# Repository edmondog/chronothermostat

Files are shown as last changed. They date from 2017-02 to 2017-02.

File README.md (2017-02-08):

# chronothermostat
Homebrewed room by room themperature control

Very rough i2c control for the temperature sensor (texas tmp 102 http://www.ti.com.cn/cn/lit/ds/symlink/tmp102.pdf)
The board has:
4 digit 7seg led display
1 encoder
1 pushbutton
485 serial interface
2 tempeature sensors
1 AC triac switch
ATMEGA328p cpu

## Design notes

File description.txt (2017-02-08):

The board controls the temperature of the room reading a tmp102 and switching a fan.
A second tmp102 controls the temperature of the heating part to avoid turning on the fan if no heat is available.
The display normally shows the room temperature.
The setpoint value is shown when pushing the button.
To avoid unwanted setpoint changing, the modification of the setpoint is subjected to password control.
The password is inserted as a number that has to be dialed using the encoder knob.
The password is fixed in code (33); once dialed the setpoint is shown and can be modified turning the encoder.
Under password 22 the temperature of the heater is shown
Under password 44 the 485 board ID is shown and made editable
A minimal communication protocol is made available to allow remote monitoring and control by a remote pc, actually a Raspberry pi.

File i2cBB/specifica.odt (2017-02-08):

Per accedere alle funzioni:

selezionare il numero relativo alla funzione e premere il pulsante.

F. 33 setpoint temperatura

F 44 indirizzo scheda

richiesta ventil e temperatura:

@xR0<CR>

vTTTT<CR>

x=indirizzo scheda

v=stato ventil

TTTT=temperatura attuale

richiesta setpoint:

@xR1<CR>

SSSS<CR>

x=indirizzo scheda

SSSS=setpoint

set setpoint:

@xW1SSSS<CR>

OK<CR>

x=indirizzo scheda

SSSS=setpoint

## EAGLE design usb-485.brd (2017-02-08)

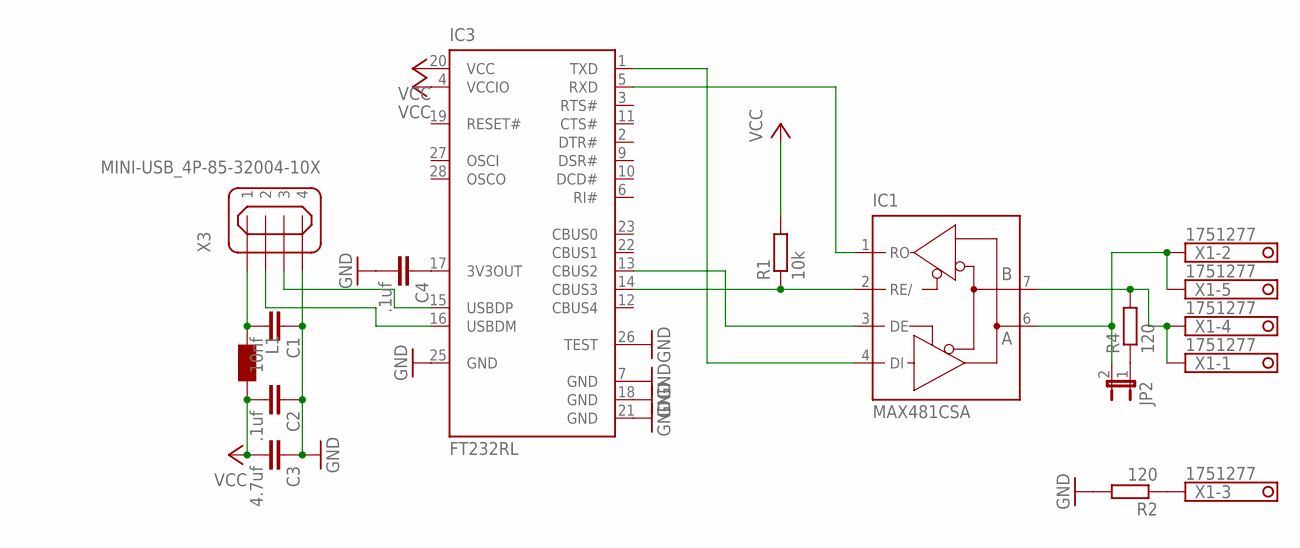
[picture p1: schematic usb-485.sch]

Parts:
C1: 10nf; C0805
C2, C4: .1uf; C1206
C3: 4.7uf; C1206
IC1: MAX481CSA; SO08
IC3: FT232RL; SSOP28
JP2: JP1E; JP1
L1: WE-CBF_1206; 1206
R1: 10k; 0207/10
R2, R4: 120; 0207/10
X1: 1751277
X3: MINI-USB_4P-85-32004-10X; 85-32004-10X

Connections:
GND: C1.1, C2.1, C3.1, C4.2, IC1.5 (GND), IC3.7 (GND), IC3.18 (GND), IC3.21 (GND), IC3.25 (GND), IC3.26 (TEST), R2.2, X3.4
unnamed: IC1.3 (DE), IC3.13 (CBUS2)
unnamed: IC1.2 (RE/), IC3.14 (CBUS3), R1.1
unnamed: IC1.7 (B), R4.2, X1.1, X1.4
unnamed: R2.1, X1.3
unnamed: JP2.1, R4.1
unnamed: C1.2, L1.1, X3.1
unnamed: IC1.6 (A), JP2.2, X1.2, X1.5
unnamed: IC3.16 (USBDM), X3.2
unnamed: IC3.15 (USBDP), X3.3
unnamed: C4.1, IC3.17 (3V3OUT)
unnamed: IC1.1 (RO), IC3.5 (RXD)
unnamed: IC1.4 (DI), IC3.1 (TXD)
VCC: C2.2, C3.2, IC1.8 (VCC), IC3.4 (VCCIO), IC3.20 (VCC), L1.2, R1.2

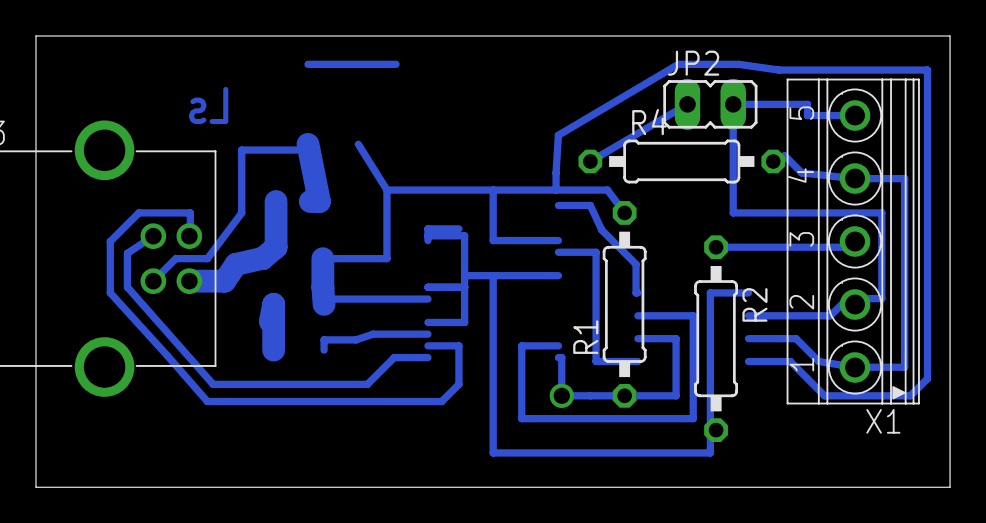
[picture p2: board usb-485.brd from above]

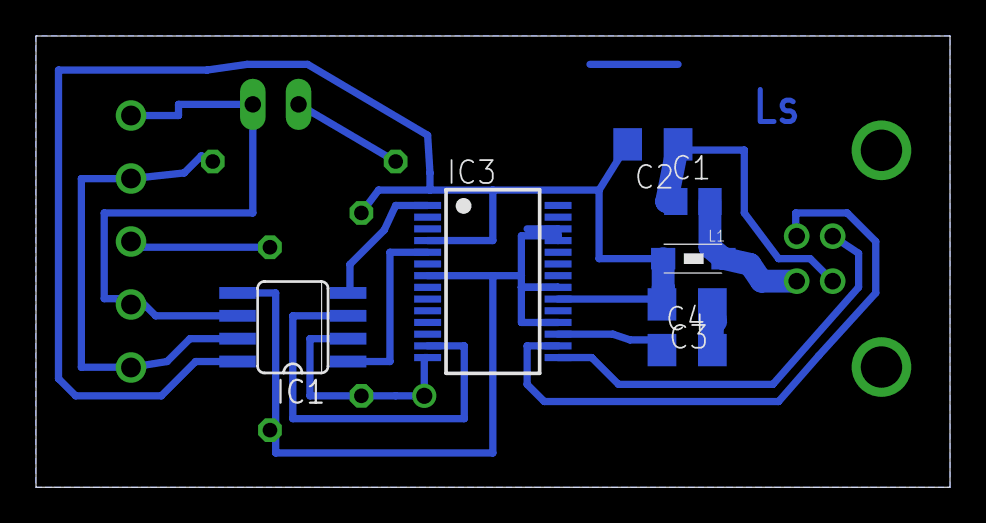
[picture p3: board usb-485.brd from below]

Board: 2 copper layers, 50.8 x 25.1 mm, 13 parts (7 on the bottom side), 14 nets.

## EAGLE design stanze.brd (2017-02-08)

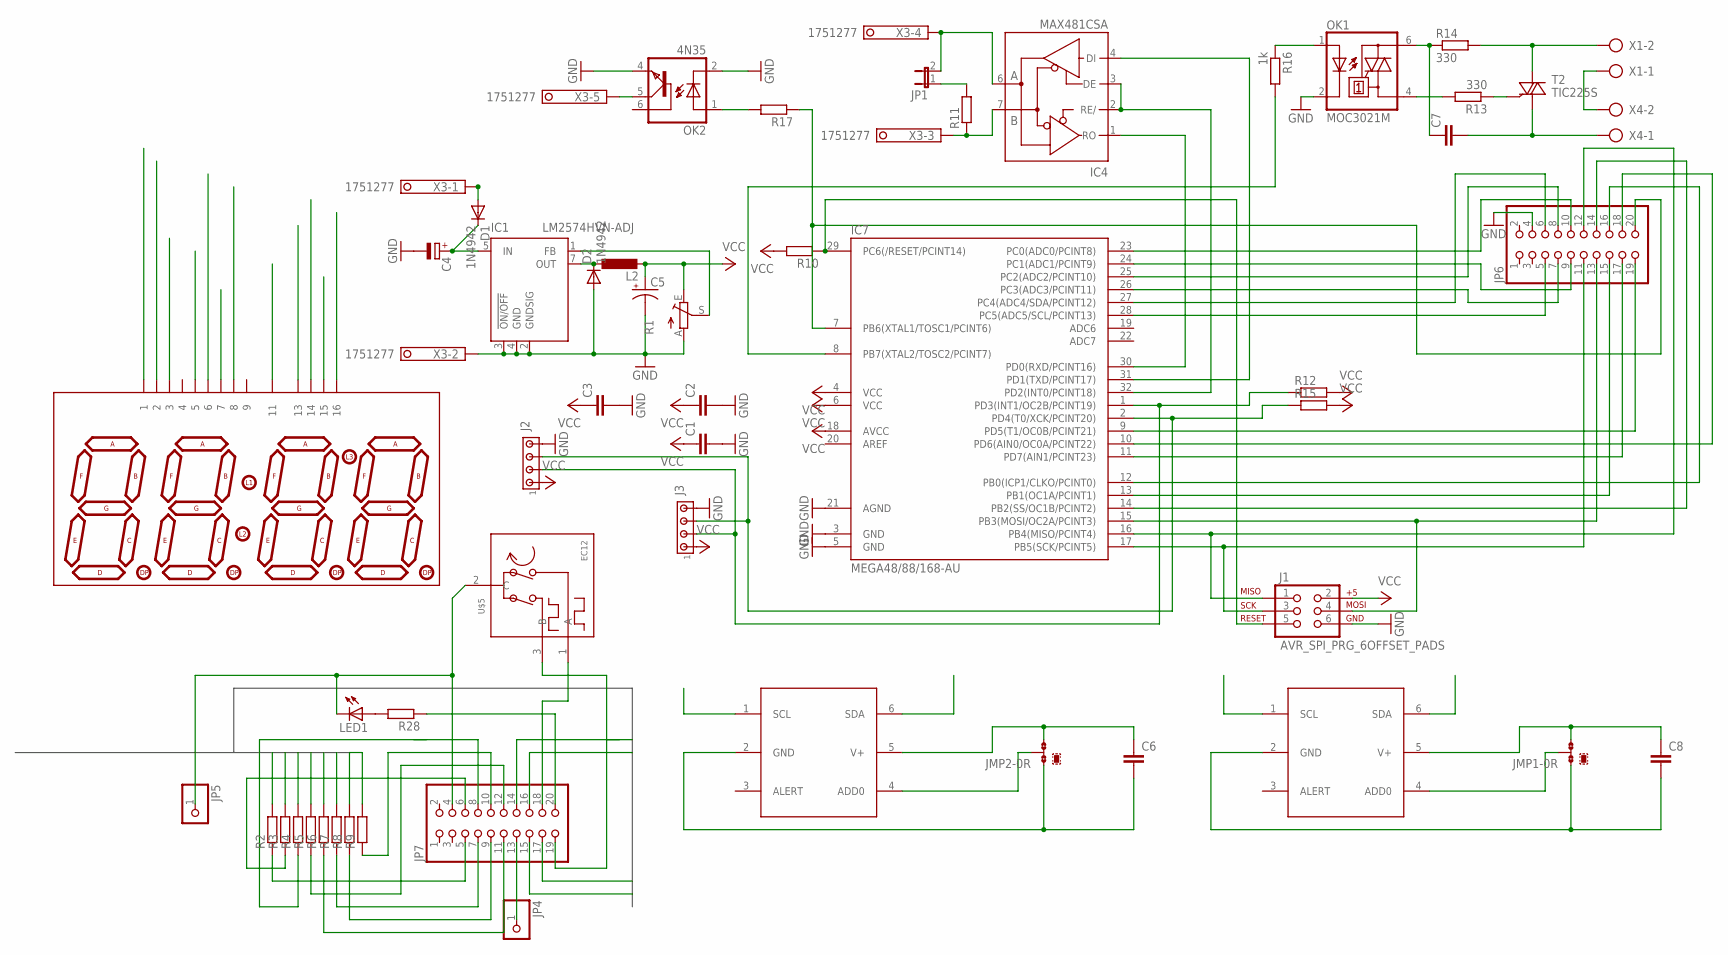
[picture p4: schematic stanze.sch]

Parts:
C1, C2, C3: C-EUC1206; C1206
C4: CPOL-EUE2,5-6E; E2,5-6E
C5: CPOL-USE5-10.5; E5-10,5
C6, C8: C-EUC0805; C0805
C7: C-EU075-032X103; C075-032X103
D1, D2: 1N4942; DO41-10
IC1: LM2574HVN-ADJ; DIL08
IC4: MAX481CSA; SO08; MPN MAX481CSA
IC7: MEGA48/88/168-AU; TQFP32-08
J1: AVR_SPI_PRG_6OFFSET_PADS; 2X3_OFFSET
J2, J3: MTA04-100; 10X04MTA
JMP1, JMP2: 0R-JUMPA; A0R-JMP
JP1: JP1E; JP1
JP4, JP5: PINHD-1X1; 1X01
JP6, JP7: PINHD-2X10; 2X10
L2: L-EUTFI0305; TFI0305
LED1: LED5MM
OK1: MOC3021M; DIL06
OK2: 4N35; DIL06
R1: TRIM_EU-B64Y; B64Y
R2, R3, R4, R5, R6, R7, R8, R9, R10, R11, R12, R15, R17, R28: R-EU_0207/10; 0207/10
R13, R14: 330; 0207/10
R16: 1k; 0207/10
T2: TIC225S; TO220DS
U$1, U$2: TMP112; SOT563
U$3: 7-SEGMENT-4DIGITPTH; 7-SEGMENT-4DIGIT
U$5: EC12
X1, X4: AK500/2
X3: 1751277

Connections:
DISPLAY1: R2.2, U$3.14
DISPLAY2: R3.2, U$3.16
DISPLAY3: R4.2, U$3.13
DISPLAY4: R5.2, U$3.3
DISPLAY5: R6.2, U$3.5
DISPLAY6: R7.2, U$3.11
DISPLAY7: R8.2, U$3.15
DISPLAY8: R9.2, U$3.7
GND: C1.2, C2.2, C3.2, C4.-, C5.-, D2.A, IC1.2 (GNDSIG), IC1.3 (!ON/OFF), IC1.4 (GND), IC4.5 (GND), IC7.3 (GND), IC7.5 (GND), IC7.21 (AGND), J1.6, J2.4, J3.4, JP6.4, OK1.2 (C), OK2.2 (C), OK2.4 (EMI), R1.A, X3.2
unnamed: C7.1, OK1.6 (A2), R14.1
unnamed: JMP2.2, U$1.4 (ADD0)
unnamed: IC7.9 (PD5(T1/OC0B/PCINT21)), JP6.19
unnamed: IC7.10 (PD6(AIN0/OC0A/PCINT22)), JP6.18
unnamed: IC7.1 (PD3(INT1/OC2B/PCINT19)), J2.2, J3.2, R12.1
unnamed: IC7.2 (PD4(T0/XCK/PCINT20)), J2.3, J3.3, R15.1
unnamed: OK2.1 (A), R17.2
unnamed: IC7.8 (PB7(XTAL2/TOSC2/PCINT7)), R16.2
unnamed: IC7.7 (PB6(XTAL1/TOSC1/PCINT6)), JP6.20, R17.1
unnamed: IC7.17 (PB5(SCK/PCINT5)), J1.3, JP6.11
unnamed: IC7.29 (PC6(/RESET/PCINT14)), J1.5, R10.1
unnamed: C8.1, JMP1.3, U$2.5 (V+)
unnamed: IC7.11 (PD7(AIN1/PCINT23)), JP6.17
unnamed: JP7.5, R2.1
unnamed: IC7.15 (PB3(MOSI/OC2A/PCINT3)), J1.4, JP6.13
unnamed: OK2.5 (COL), X3.5
unnamed: IC7.12 (PB0(ICP1/CLKO/PCINT0)), JP6.16
unnamed: IC7.13 (PB1(OC1A/PCINT1)), JP6.15
unnamed: IC7.14 (PB2(SS/OC1B/PCINT2)), JP6.14
unnamed: IC7.23 (PC0(ADC0/PCINT8)), JP6.10
unnamed: IC7.28 (PC5(ADC5/SCL/PCINT13)), JP6.5
unnamed: JP7.6, R3.1
unnamed: R13.1, T2.G
unnamed: C6.1, JMP2.3, U$1.5 (V+)
unnamed: IC7.24 (PC1(ADC1/PCINT9)), JP6.9
unnamed: OK1.4 (A1), R13.2
unnamed: IC4.4 (DI), IC7.31 (PD1(TXD/PCINT17))
unnamed: IC4.1 (RO), IC7.30 (PD0(RXD/PCINT16))
unnamed: IC4.2 (RE/), IC4.3 (DE), IC7.32 (PD2(INT0/PCINT18))
unnamed: JP7.18, U$5.1 (A)
unnamed: IC7.26 (PC3(ADC3/PCINT11)), JP6.7
unnamed: IC4.7 (B), R11.1, X3.3
unnamed: IC4.6 (A), JP1.2, X3.4
unnamed: D2.C, IC1.7 (OUT), L2.1
unnamed: IC1.1 (FB), R1.S
unnamed: C4.+, D1.C, IC1.5 (IN)
unnamed: JP1.1, R11.2
unnamed: D1.A, X3.1
unnamed: IC7.25 (PC2(ADC2/PCINT10)), JP6.8
unnamed: JP7.7, R7.1
unnamed: R14.2, T2.A2, X1.2
unnamed: IC7.16 (PB4(MISO/PCINT4)), J1.1, JP6.12
unnamed: JP7.8, R4.1
unnamed: JP7.9, R8.1
unnamed: JP7.10, R9.1
unnamed: JP7.11, R6.1
unnamed: JP7.12, R5.1
unnamed: JP4.1, JP7.13
unnamed: C7.2, T2.A1, X4.1
unnamed: X1.1, X4.2
unnamed: OK1.1 (A), R16.1
unnamed: IC7.27 (PC4(ADC4/SDA/PCINT12)), JP6.6
unnamed: JP7.19, U$5.3 (B)
unnamed: JP5.1, JP7.4, LED1.K (C), U$5.2 (C)
unnamed: JP7.20, R28.1
unnamed: LED1.A, R28.2
unnamed: C6.2, JMP2.1, U$1.2 (GND)
unnamed: JMP1.2, U$2.4 (ADD0)
unnamed: C8.2, JMP1.1, U$2.2 (GND)
S1: JP7.14, U$3.1
S2: JP7.15, U$3.2
S3: JP7.16, U$3.6
S4: JP7.17, U$3.8
VCC: C1.1, C2.1, C3.1, C5.+, IC4.8 (VCC), IC7.4 (VCC), IC7.6 (VCC), IC7.18 (AVCC), J1.2, J2.1, J3.1, L2.2, R1.E, R10.2, R12.2, R15.2

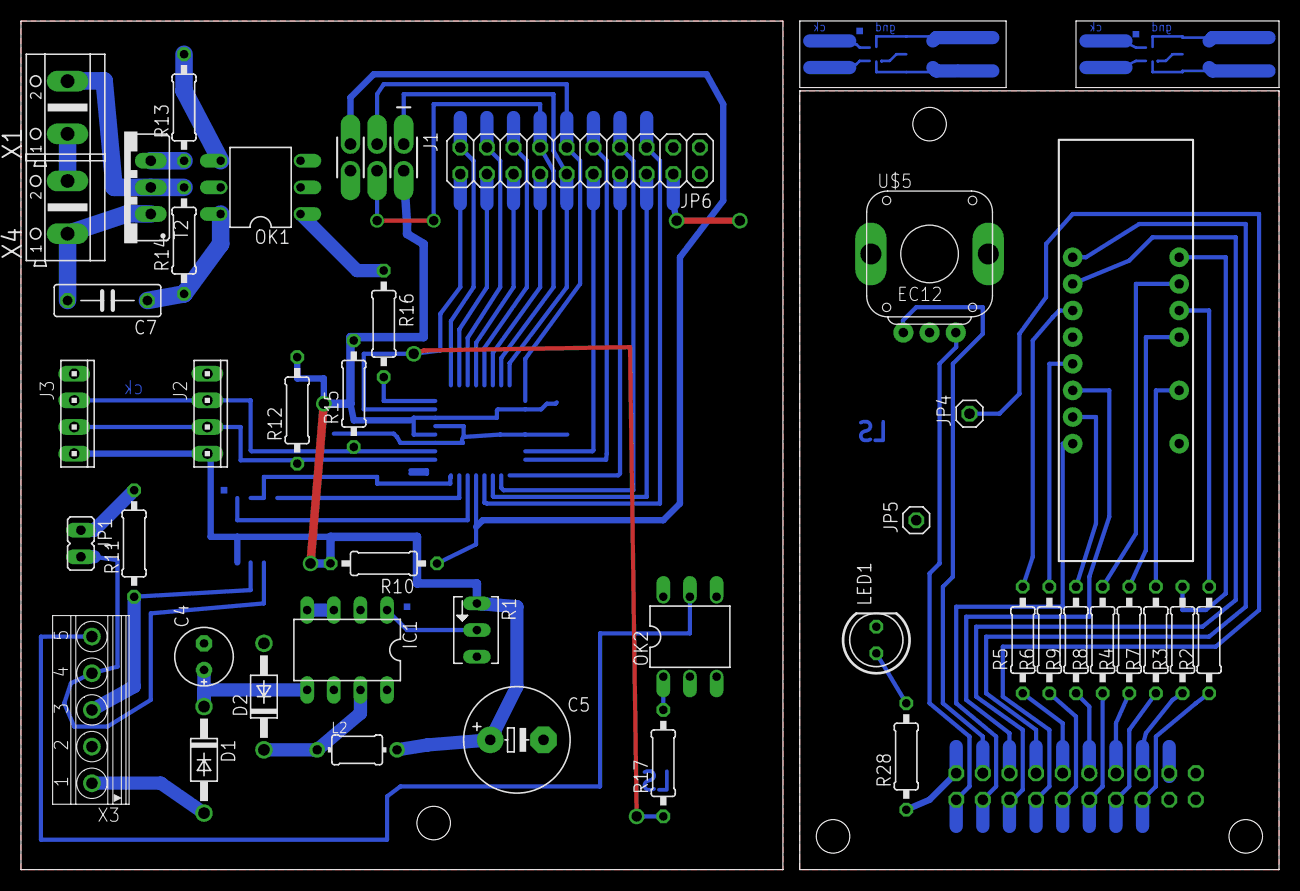
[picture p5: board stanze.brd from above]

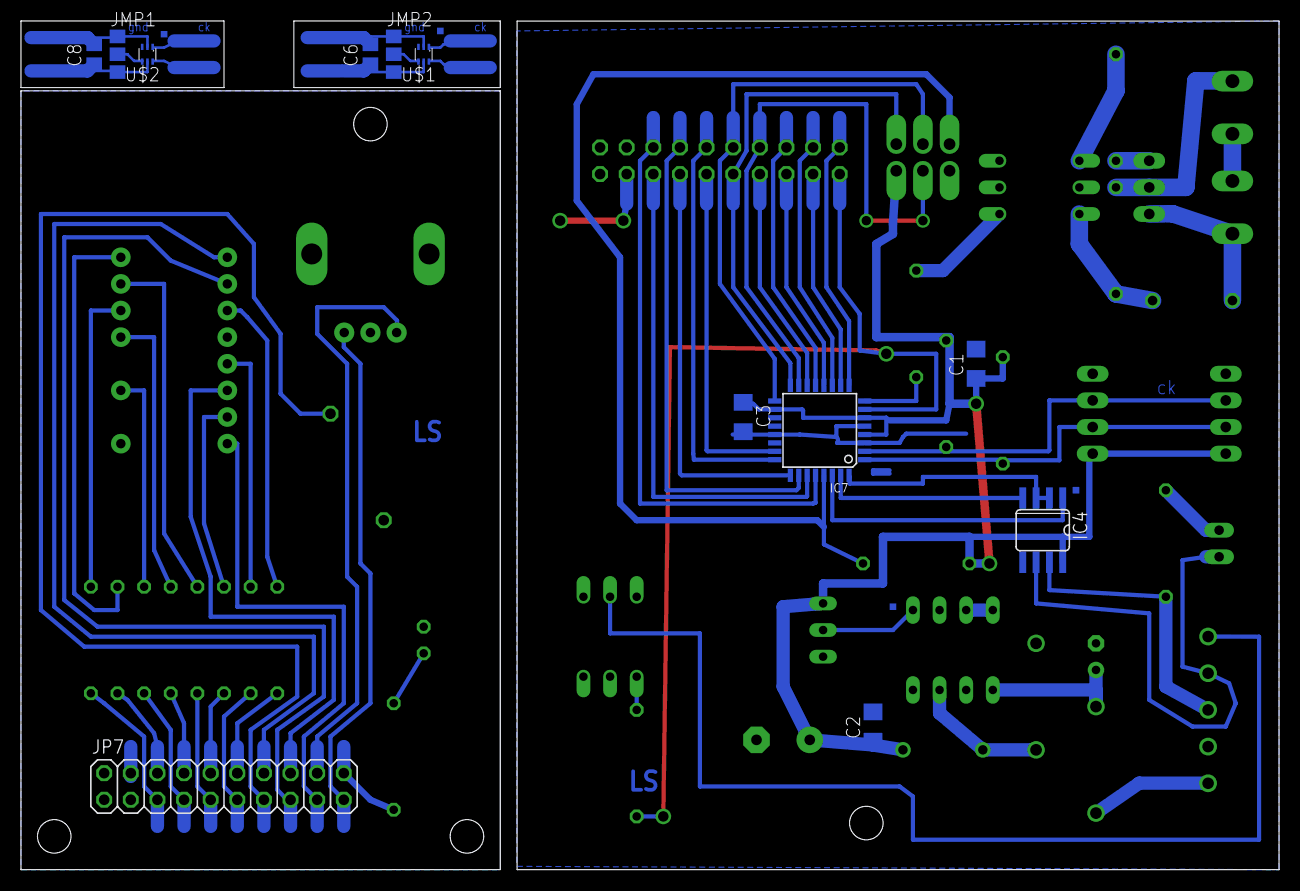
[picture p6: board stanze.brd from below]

Board: 2 copper layers, 120.0 x 81.0 mm, 53 parts (12 on the bottom side), 73 nets.

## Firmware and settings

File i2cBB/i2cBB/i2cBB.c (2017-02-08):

#include <avr/io.h>
#include <avr/interrupt.h>
#include <avr/eeprom.h>
#include <string.h>

#define F_CPU 8000000
#define BAUD 19200
#include <util/setbaud.h>
#define sbi(P, B) (P |= _BV(B))
#define cbi(s,b) (s &= ~(_BV(b)))

#define RS485DIR_DDR DDRD
#define RS485DIR_PORT PORTD
#define RS485DIR_BIT PD2

#define OUT_0 PB7
#define OUT_0_PORT PORTB
#define OUT_0_DDR DDRB
#define LED_1 PB6
#define LED_1_PORT PORTB
#define LED_1_DDR DDRB
#define ENABLE_0 PD7
#define ENABLE_0_PORT PORTD
#define ENABLE_0_DDR DDRD
#define ENABLE_1 PB0
#define ENABLE_1_PORT PORTB
#define ENABLE_1_DDR DDRB
#define ENABLE_2 PB1
#define ENABLE_2_PORT PORTB
#define ENABLE_2_DDR DDRB
#define ENABLE_3 PB2
#define ENABLE_3_PORT PORTB
#define ENABLE_3_DDR DDRB
#define FASE_1 PD6
#define FASE_1_PORT PORTD
#define FASE_1_PIN PIND
#define FASE_1_DDR DDRD
#define FASE_2 PD5
#define FASE_2_PORT PORTD
#define FASE_2_PIN PIND
#define FASE_2_DDR DDRD
#define PULS PB3
#define PULS_PORT PORTB
#define PULS_PIN PINB
#define PULS_DDR DDRB
#define SEG_A PC5
#define SEG_A_PORT PORTC
#define SEG_A_DDR DDRC
#define SEG_B PC4
#define SEG_B_PORT PORTC
#define SEG_B_DDR DDRC
#define SEG_C PC2
#define SEG_C_PORT PORTC
#define SEG_C_DDR DDRC
#define SEG_D PB4
#define SEG_D_PORT PORTB
#define SEG_D_DDR DDRB
#define SEG_E PB5
#define SEG_E_PORT PORTB
#define SEG_E_DDR DDRB
#define SEG_F PC3
#define SEG_F_PORT PORTC
#define SEG_F_DDR DDRC
#define SEG_G PC1
#define SEG_G_PORT PORTC
#define SEG_G_DDR DDRC
#define SEG_P PC0
#define SEG_P_PORT PORTC
#define SEG_P_DDR DDRC
unsigned char caratteri[20]={0x3F,0x06,0x5B,0x4F,0x66,0x6D,0x7D,0x07,0x7F,0x6F,0xBF,0x86,0xDB,0xCF,0xE6,0xED,0xFD,0x87,0xFF,0xEF};
volatile int pos=0;
volatile unsigned char pd;
unsigned char v0=0;
unsigned char v1=0;
unsigned char v2=0;
unsigned char v3=0;
unsigned char w0=0;
unsigned char w1=0;
unsigned char w2=0;
unsigned char w3=0;
unsigned char s0=0;
unsigned char s1=0;
unsigned char s2=0;
unsigned char s3=0;
unsigned long v_acc;
unsigned long w_acc;
int v,w,termo;
int setp=0;
unsigned char modo=0;
int pos0=0;
volatile unsigned int t0;
volatile unsigned char ttd=0;
volatile unsigned char d0=0;
volatile unsigned char d1=0;
volatile unsigned char d2=0;
volatile unsigned char d3=0;
unsigned char button_up=0;
unsigned char button_dn=0;
unsigned char button_old=0;
void cifra(unsigned char n, unsigned char c);

#define T_OUT 40000

// Port for the I2C
#define I2C_DDR DDRD
#define I2C_PIN PIND
#define I2C_PORT PORTD
#define DEV0 10010000
#define DEV1 10010010
#define I2C_R 1
#define I2C_W 0

// Pins to be used in the bit banging
#define I2C_CLK 4
#define I2C_DAT 3

#define I2C_DATA_HI()\
I2C_PORT |= (1 << I2C_DAT);\
I2C_DDR &= ~ (1 << I2C_DAT);
#define I2C_DATA_LO()\
I2C_PORT &= ~ (1 << I2C_DAT);\
I2C_DDR |= (1 << I2C_DAT);

#define I2C_CLOCK_HI()\
I2C_PORT |= (1 << I2C_CLK);\
I2C_DDR &= ~ (1 << I2C_CLK);
#define I2C_CLOCK_LO()\
I2C_PORT &= ~ (1 << I2C_CLK);\
I2C_DDR |= (1 << I2C_CLK);

void I2C_Init();

volatile unsigned char res=0,n=0,device=0;
volatile int t=0,tt=0,tv0=0,tv1=0;
volatile unsigned char i2c_step=0, clock_req=0;
volatile unsigned char tv1_valid=0, tv0_valid=0;
volatile unsigned char chrno=0,chrr,chrv1[16],chrv2[16],received;
unsigned char txbuf[32];
unsigned char p0=0;
unsigned char ptx=0;
unsigned char me;
unsigned char req=0;

ISR(USART_RX_vect)
{
	chrr=UDR0;
	if(chrr)
	{
		chrv1[chrno++]=chrr;
		chrno&=0x0f;
		if(chrr==13)
		{
			strncpy(chrv2,chrv1,chrno);
			chrno=0;
			received=1;
		}
	}
}

ISR(PCINT2_vect)
{
	if(bit_is_set(FASE_1_PIN,FASE_1))
	{
		if(bit_is_set(FASE_2_PIN,FASE_2) && bit_is_clear(pd,FASE_2)) // difu
				pos++;
		if(bit_is_set(pd,FASE_2) && bit_is_clear(FASE_2_PIN,FASE_2)) // difd
				pos--;
		if(pos>9999)
			pos=0;
		if(pos<0)
			pos=9999;
	}	
	pd=PIND;
}


ISR(TIMER0_COMPA_vect)
{
	switch(clock_req)
	{
	case 0:
		switch(i2c_step)
		{
		case 0:	// start
			I2C_DATA_LO();
			break;
		case 1:
			I2C_CLOCK_LO();
			break;
			
		case 2:	// DEV0 10010010
		case 5:
			I2C_DATA_HI();
			clock_req=1;
			break;
		case 8:
			if(device==1)
			{
				I2C_DATA_HI();
			}
			else
			{
				I2C_DATA_LO();
			}
			clock_req=1;
			break;
		case 3:
		case 4:
		case 6:
		case 7:
		case 9: // W negato
			I2C_DATA_LO();
			clock_req=1;
			break;

		case 10: // read ack
			I2C_DATA_HI();
			I2C_CLOCK_HI();
			break;
		case 11:
			//			c = I2C_PIN ;
			//			d = (1<< I2C_DAT);
			//			e=c&d;
			I2C_DATA_LO();
			I2C_CLOCK_LO();
			break;

		case 12: // c=0;
		case 13:
		case 14:
		case 15:
		case 16:
		case 17:
		case 18:
		case 19:
			I2C_DATA_LO();
			clock_req=1;
			break;

		case 20: // read ack
			I2C_DATA_HI();
			I2C_CLOCK_HI();
			break;
		case 21:
			//			c = (I2C_PIN & (1<< I2C_DAT));
			I2C_DATA_LO();
			I2C_CLOCK_LO();
			break;
			
		case 22: // STOP
			I2C_DATA_LO();
			break;
		case 23:
			I2C_CLOCK_HI();
			break;
		case 24:
			I2C_DATA_HI();
			break;
			
		case 25: // START
			I2C_DATA_LO();
			break;

		case 26:
			I2C_CLOCK_LO();
			break;

		case 27: // DEV0 10010011
		case 30:
		case 34: // Read
			I2C_DATA_HI();
			clock_req=1;
			break;
		case 33:
			if(device==1)
			{
				I2C_DATA_HI();
			}
			else
			{
				I2C_DATA_LO();
			}
			clock_req=1;
			break;
		case 28:
		case 29:
		case 31:
		case 32:
			I2C_DATA_LO();
			clock_req=1;
			break;
			
		case 35: // read ack
			I2C_DATA_HI();
			I2C_CLOCK_HI();
			break;
		case 36:
			//			c = (I2C_PIN & (1<< I2C_DAT));
			res=0;
			I2C_DATA_LO();
			I2C_CLOCK_LO();
			break;

		case 37:
		case 38:
		case 39:
		case 40:
		case 41:
		case 42:
		case 43:
		case 44:
			clock_req=10;
			break;
		case 45:
			I2C_DATA_LO();
			clock_req=1;
			break;
		case 46:
			t=res;
			t <<= 8;
			break;
			
		case 47: // 2nd byte temp
			res=0;
			I2C_DATA_HI();
			break;

		case 48:
		case 49:
		case 50:
		case 51:
		case 52:
		case 53:
		case 54:
		case 55:
			clock_req=10;
			break;

		case 56:
			I2C_DATA_LO();
			clock_req=1;
			break;
		case 57:
			t+=res;
			t >>= 4;
			tt+=t;
			n++;
			I2C_CLOCK_HI();
			break;
		case 58:
			I2C_DATA_HI();
			break;
		case 59:
			if(n==10)
			{
				if(device==1)
				{
					tv1=(tt>>4);
					tv1_valid=1;
					device=0;
				}
				else
				{
					tv0=(tt>>4);
					tv0_valid=1;
					device=1;
				}
				tt=0;
				n=0;
			}
			break;
		case 60:
			#define ENDSEQ 60
			break;
			
		}
		break;
		
	case 1:
		I2C_CLOCK_HI();
		i2c_step--;
		clock_req=2;
		break;
	case 2:
		I2C_CLOCK_LO();
		i2c_step--;
		clock_req=0;
		break;
	case 10:
		res<<=1;
		I2C_DATA_HI();
		I2C_CLOCK_HI();
		i2c_step--;
		clock_req=11;
		break;
	case 11:
		if((I2C_PIN & (1<< I2C_DAT)))
			res|=1;
		I2C_CLOCK_LO();
		i2c_step--;
		clock_req=0;
		break;
	}
	if(i2c_step!=ENDSEQ)
		i2c_step++;
	else
		i2c_step=0;

	t0++;
	ttd++;
	switch(ttd)
	{
		case 1:
			cifra(caratteri[d0],0);
			break;
		case 2:
			cifra(caratteri[d1],1);
			break;
		case 3:
			cifra(caratteri[d2],2);
			break;
		case 4:
			cifra(caratteri[d3],3);
			ttd=0;
			break;
	}

}

void cifra(unsigned char n, unsigned char c)
{
	sbi(ENABLE_0_PORT,ENABLE_0);
	sbi(ENABLE_1_PORT,ENABLE_1);
	sbi(ENABLE_2_PORT,ENABLE_2);
	sbi(ENABLE_3_PORT,ENABLE_3);
	
	if(n&1)
		sbi(SEG_A_PORT,SEG_A);
	else
		cbi(SEG_A_PORT,SEG_A);
	
	if(n&2)
		sbi(SEG_B_PORT,SEG_B);
	else
		cbi(SEG_B_PORT,SEG_B);
	
	if(n&4)
		sbi(SEG_C_PORT,SEG_C);
	else
		cbi(SEG_C_PORT,SEG_C);
	
	if(n&8)
		sbi(SEG_D_PORT,SEG_D);
	else
		cbi(SEG_D_PORT,SEG_D);
	
	if(n&16)
		sbi(SEG_E_PORT,SEG_E);
	else
		cbi(SEG_E_PORT,SEG_E);
	
	if(n&32)
		sbi(SEG_F_PORT,SEG_F);
	else
		cbi(SEG_F_PORT,SEG_F);
	
	if(n&64)
		sbi(SEG_G_PORT,SEG_G);
	else
		cbi(SEG_G_PORT,SEG_G);
	
	if(n&128)
		sbi(SEG_P_PORT,SEG_P);
	else
		cbi(SEG_P_PORT,SEG_P);

	switch(c)
	{
	case 0:
		cbi(ENABLE_0_PORT,ENABLE_0);
		break;
	case 1:
		cbi(ENABLE_1_PORT,ENABLE_1);
		break;
	case 2:
		cbi(ENABLE_2_PORT,ENABLE_2);
		break;
	case 3:
		cbi(ENABLE_3_PORT,ENABLE_3);
		break;
	}
}


void display()
{
	switch(modo)
	{
	case 0:
		if(bit_is_clear(PULS_PIN,PULS))
		{
			s0=setp%10;
			s1=(setp/10)%10;
			s2=(setp/100)%10;
			s3=(setp/1000)%10;
			d0=s0;
			d1=s1+10;
			d2=s2;
			d3=s3;
		}
		else
		{
			d0=v0;
			d1=v1+10;
			d2=v2;
			d3=v3;
		}
		if(pos!=pos0)
		{
			pos=0;
			t0=0;
			modo=1;
		}
		break;
		
	case 1:
		d0=pos%10;
		d1=(pos/10)%10;
		d2=(pos/100)%10;
		d3=(pos/1000)%10;
		if(button_dn)
		{
			if(pos==33) // modify setpoint
			{
				modo=2;
				pos=setp;
				t0=0;
			}
			else
			if(pos==44) // modify me
			{
				modo=4;
				pos=me;
				t0=0;
			}
			else
			if(pos==22) // show termo
			{
				modo=6;
				pos=me;
				t0=0;
			}
			else
			{
				modo=0;
			}
			pos0=pos;
		}
		if(t0>T_OUT)
		{
			modo=0;
			pos0=pos;
		}
		if(pos!=pos0)
		{
			t0=0;
			pos0=pos;
		}
		break;
	
	case 2: // aspetta il rilascio del pulsante
		if(button_up)
		{
			modo++;
		}
		break;

	case 3:
		d0=pos%10;
		d1=((pos/10)%10)+10;
		d2=(pos/100)%10;
		d3=(pos/1000)%10;
		if(button_dn)
		{
			modo=0;
			setp=pos;
			eeprom_update_word (0,setp);
		}
		if(t0>T_OUT)
		{
			modo=0;
			pos0=pos;
		}
		if(pos!=pos0)
		{
			t0=0;
			pos0=pos;
		}
		break;

	case 4: // aspetta il rilascio del pulsante
		if(button_up)
		{
			modo++;
		}
		break;

	case 5:
		if(pos<0)
			pos=0;
		if(pos>255)
			pos=0;
		d0=pos%10;
		d1=((pos/10)%10)+10;
		d2=(pos/100)%10;
		d3=(pos/1000)%10;
		if(button_dn)
		{
			modo=0;
			me=pos;
			eeprom_update_word(2,pos);
		}
		if(t0>T_OUT)
		{
			modo=0;
			pos0=pos;
		}
		if(pos!=pos0)
		{
			t0=0;
			pos0=pos;
		}
		break;
	case 6: // aspetta il rilascio del pulsante
		if(button_up)
		{
			modo++;
		}
		break;

	case 7:
		d0=termo%10;
		d1=((termo/10)%10)+10;
		d2=(termo/100)%10;
		d3=(termo/1000)%10;
		if(button_dn || t0>T_OUT)
		{
			modo=0;
		}
		break;

	}
}


void Add_tx(unsigned char car)
{
	if(((p0+1)&31)!=ptx)
	{
		txbuf[p0++]=car;
		p0&=31;
	}
}

void Add_uint_tx(unsigned int i)
{
	if(i==0)
		Add_tx('0');
	else
	{
		if(i<10)
			Add_tx('0'+i);
		else
		{
			if(i<100)
			{
				Add_tx('0'+i%10);
				Add_tx('0'+i/10);
			}
			else
			{
				if(i<1000)
				{
					Add_tx('0'+i%10);
					Add_tx('0'+(i/10)%10);
					Add_tx('0'+(i/100));
				}
				else
				{
					if(i<10000)
					{
						Add_tx('0'+i%10);
						Add_tx('0'+(i/10)%10);
						Add_tx('0'+(i/100)%10);
						Add_tx('0'+(i/1000));
					}
					else
						Add_tx('E');
				}
			}
		}
	}
}
void Spool_tx(void)
{
	// 485
	UBRR0H = UBRRH_VALUE;
	UBRR0L = UBRRL_VALUE;
	#if USE_2X
	UCSR0A |= (1 << U2X0);
	#else
	UCSR0A &= ~(1 << U2X0);
	#endif
	/* Set frame format: 8data */
	UCSR0C = (3<<UCSZ00);
	sbi(UCSR0B,TXEN0);
	sbi(UCSR0B,RXEN0);
	sbi(UCSR0B,RXCIE0);

	if(bit_is_set(UCSR0A,UDRE0))
	{
		if(ptx!=p0)
		{
			sbi(RS485DIR_PORT,RS485DIR_BIT);
			UDR0=txbuf[ptx++];
			ptx&=31;
		}
		else
		{
			if(bit_is_set(UCSR0A,TXC0))
			{
				cbi(RS485DIR_PORT,RS485DIR_BIT);
				sbi(UCSR0A,TXC0);
			}
		}
		if(received)
		{
			if(chrv2[0]=='@' && chrv2[1]=='z' && chrv2[2]!=13 && chrv2[3]==13)
			{
				// scrive l'id della scheda (solo una scheda deve essere collegata)
				eeprom_update_byte(2,chrv2[2]);
				me=chrv2[2];
				Add_tx(10);
				Add_tx(13);
				Add_tx('M');
				Add_tx('e');
				Add_tx('=');
				Add_tx(me);
				Add_tx(10);
				Add_tx(13);
			}
			if(chrv2[0]=='@' && chrv2[1]==me && (chrv2[2]=='R' || chrv2[2]=='r') && chrv2[3]=='0')
			{
				// temperatura
				Add_tx(req+'0');
				Add_tx(v3+'0');
				Add_tx(v2+'0');
				Add_tx(v1+'0');
				Add_tx(v0+'0');
				Add_tx(s3+'0');
				Add_tx(s2+'0');
				Add_tx(s1+'0');
				Add_tx(s0+'0');
				Add_tx(13);
			}
			if(chrv2[0]=='@' && chrv2[1]==me && (chrv2[2]=='R' || chrv2[2]=='r') && chrv2[3]=='1')
			{
				// setp
				Add_tx(s3+'0');
				Add_tx(s2+'0');
				Add_tx(s1+'0');
				Add_tx(s0+'0');
				Add_tx(13);
			}
			if(chrv2[0]=='@' && chrv2[1]==me && (chrv2[2]=='W' || chrv2[2]=='w') && chrv2[3]=='1' && chrv2[4]!=13 && chrv2[5]!=13 && chrv2[6]!=13 && chrv2[7]!=13 && chrv2[8]==13)
			{
				//
				s3=chrv2[4]-'0';
				s2=chrv2[5]-'0';
				s1=chrv2[6]-'0';
				s0=chrv2[7]-'0';
				setp=((chrv2[4]-'0')*1000)+((chrv2[5]-'0')*100)+((chrv2[6]-'0')*10)+(chrv2[7]-'0');
				eeprom_update_word (0,setp);
				Add_tx('O');
				Add_tx('K');
				Add_tx(13);
			}
			received=0;
		}
	}
}
void Flush(void)
{
	p0=0;
}
#include <avr/io.h>

int main(void)
{
	int val0,val1;
	// I/O
	cbi(LED_1_PORT,LED_1);
	sbi(LED_1_DDR, LED_1);
	// IO SETUP
	sbi(OUT_0_DDR,OUT_0);
	sbi(SEG_A_DDR,SEG_A);
	sbi(SEG_B_DDR,SEG_B);
	sbi(SEG_C_DDR,SEG_C);
	sbi(SEG_D_DDR,SEG_D);
	sbi(SEG_E_DDR,SEG_E);
	sbi(SEG_F_DDR,SEG_F);
	sbi(SEG_G_DDR,SEG_G);
	sbi(SEG_P_DDR,SEG_P);
	sbi(ENABLE_0_DDR,ENABLE_0);
	sbi(ENABLE_1_DDR,ENABLE_1);
	sbi(ENABLE_2_DDR,ENABLE_2);
	sbi(ENABLE_3_DDR,ENABLE_3);
	
	
	cbi(FASE_1_DDR,FASE_1);
	cbi(FASE_2_DDR,FASE_2);
	sbi(FASE_1_PORT,FASE_1);
	sbi(FASE_2_PORT,FASE_2);
	cbi(PULS_DDR,PULS);
	sbi(PULS_PORT,PULS);

	// IO INTERRUPT
	sbi(PCICR,PCIE2);
	sbi(PCMSK2,PCINT21);
//	sbi(PCMSK2,PCINT22);
	
	I2C_Init();
	// TIMER0
	sbi(TCCR0A,WGM01);
	cbi(TCCR0B,CS00);
	sbi(TCCR0B,CS01);
	cbi(TCCR0B,CS02);
	OCR0A=0xF0;
	sbi(TIMSK0,OCIE0A);

// 485
	cbi(RS485DIR_PORT,RS485DIR_BIT);
	sbi(RS485DIR_DDR, RS485DIR_BIT);
	UBRR0H = UBRRH_VALUE;
	UBRR0L = UBRRL_VALUE;
	#if USE_2X
		UCSR0A |= (1 << U2X0);
	#else
		UCSR0A &= ~(1 << U2X0);
	#endif
	/* Set frame format: 8data */
	UCSR0C = (3<<UCSZ00);
	sbi(UCSR0B,TXEN0);
	sbi(UCSR0B,RXEN0);
	sbi(UCSR0B,RXCIE0);

	me=eeprom_read_word (2);

	setp=eeprom_read_word (0);
	if(setp>999 || setp<0)
		setp=130;

	s0=setp%10;
	s1=(setp/10)%10;
	s2=(setp/100)%10;
	s3=(setp/1000)%10;

	sei();

	val0=0;
	val1=0;
	
    while(1)
    {

		Spool_tx();
		if(tv0_valid)
		{
			val0=tv0;
			tv0_valid=0;
		}
		
		if(tv1_valid)
		{
			val1=tv1;
			tv1_valid=0;
			termo=val1;		
		}

		v0=val0%10;
		v1=(val0/10)%10;
		v2=(val0/100)%10;
		v3=(val0/1000)%10;

		if((val0+3)<setp)
		{
			sbi(LED_1_PORT,LED_1);
			req=1;
		}			
		if(val1>300 && (val0+3)<setp)
		{
			sbi(OUT_0_PORT,OUT_0);
		}
		if((val0)>setp)
		{
			cbi(LED_1_PORT,LED_1);
			req=0;
		}
		if(val1<290 || (val0)>setp)
		{
			cbi(OUT_0_PORT,OUT_0);
		}

		if(bit_is_clear(PULS_PIN,PULS)&& button_old==0)
			button_dn=1; // difu
		else
			button_dn=0;
		if(bit_is_set(PULS_PIN,PULS)&& button_old==1)
			button_up=1; // difd
		else
			button_up=0;

		if(bit_is_clear(PULS_PIN,PULS))
			button_old=1;
		else
			button_old=0;

		display();
		
	}
}





// Inits bitbanging port, must be called before using the functions below
//
void I2C_Init()
{
	I2C_PORT &= ~ ((1 << I2C_DAT) | (1 << I2C_CLK));

	I2C_CLOCK_HI();
	I2C_DATA_HI();

}

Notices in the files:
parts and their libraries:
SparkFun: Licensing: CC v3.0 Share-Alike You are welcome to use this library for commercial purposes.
